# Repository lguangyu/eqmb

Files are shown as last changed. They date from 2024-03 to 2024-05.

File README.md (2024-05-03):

# Emergency Question Mark Button (EQMB)

For a certain professor that uses a lot of question marks when reviewing/commenting our manuscripts.
Some question marks are subject to lurk in the maintext because the said professor refuses to use the Word's "comment" feature. Those lurking question marks are unprecedented gifts to any editor whom they *may not* concern.

This project has an alt-name: the <b>EMERGENCY BUTTON for a certain PROFESSOR'S RAGE</b>, or <b><font color="#8080ff">EBPR</font></b>.

## Features

This is an application based on ESP32 microcontroller. It comes with a top Rage-Button, a BT control button, a micro-USB charging port and a power switch.

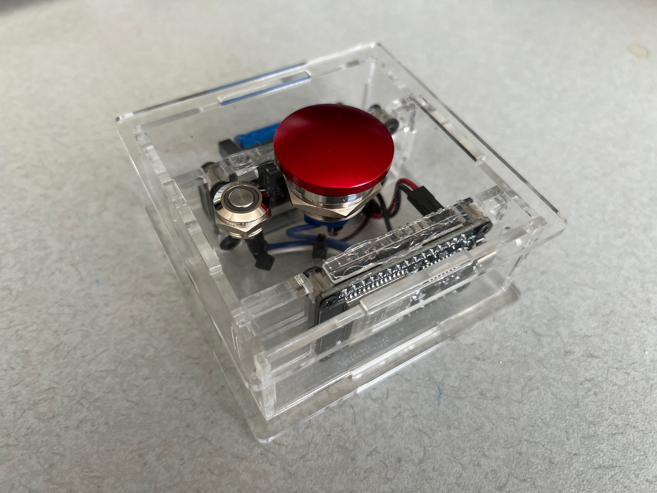
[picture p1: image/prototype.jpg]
Prototype


### Power

This device is powered by a single 16340 lithium battery that can be recharged from micro-USB. There is a power switch on the bottom side of the device.

### Rage-Button

When pressed, the top button sends a <kbd>?</kbd> character to the host computer. Follow-up presses within 750ms of the preceding one will send more <kbd>?</kbd>s, up to 6 in a single press. This feature is called "rage streak".

### Bluetooth (BT) Control Button

When the BT control button is pushed, the device will enter BT pairing mode (with blue LED flashing) for accepting new device pairings. A second push will exit the pairing mode.

Releasing the BT control button after holding it for over 5sec will trigger a hard reset of the device, deleting all paired devices.

### Sleep Mode

The device will enter sleep mode when left idle for over 2min. Push the BT control button can wake it up.

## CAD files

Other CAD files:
cad/box.dwg

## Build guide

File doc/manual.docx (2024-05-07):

# Emergency Button for a certain Professor’s Rage

# = Codename: EBPR =

# SYNOPSIS

A button for a certain professor to rage-press when reviewing manuscripts and abstracts. This button allows the certain professor to rapidly send “?” marks via Bluetooth. It is a significant time saver and emergency solution for imminent “?” satisfaction.

# QUICKSTART GUIDE

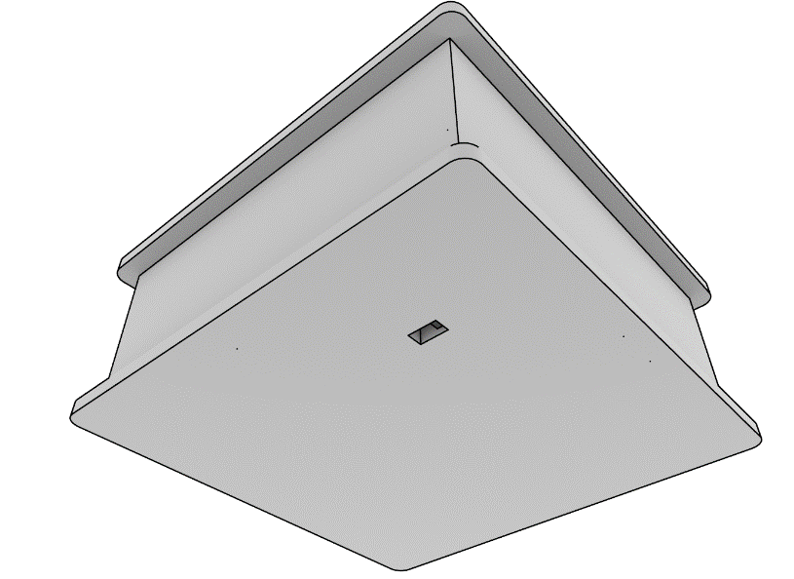
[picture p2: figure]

| (1) Switch on.
| (2) Tap to enter BT paring mode. Built-in LEDs will start to blink.

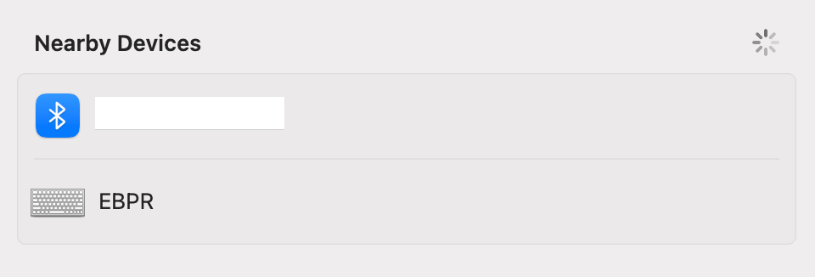
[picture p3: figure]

| (3) Connect via Bluetooth. For Mac, find more information about Bluetooth connection here (https://support.apple.com/guide/mac-help/connect-a-bluetooth-device-blth1004/mac); for Windows, here (https://support.microsoft.com/en-us/windows/pair-a-bluetooth-device-in-windows-2be7b51f-6ae9-b757-a3b9-95ee40c3e242).
| (4) Once connected, press the red button to enjoy the rage-pressing. The faster spamming this button, the more “?” will be sent.

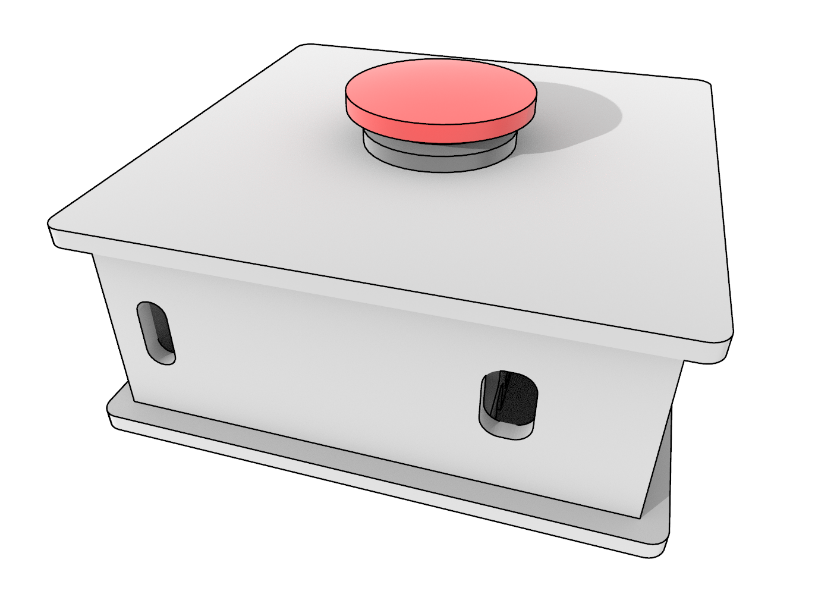
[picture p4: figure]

| Low battery In case of low battery, charging via micro-USB through this port. The LED near the battery will turn green when fully charged.
| Sleep mode Device will enter sleep mode after 120s of no action. Tap to wake it up.
| Bluetooth resetting While not in sleep mode, holding down this button for at least 10s to reset the Bluetooth pairing.

# TECHNICAL PARAMETERS

Weight | 200g (battery included)
Dimensions | 90mm (W) × 90mm (L) × 50mm (H)
MCU | 1× ESP32-WROOM
MCU VCC | 3.3V, internally regulated
Working current | Not rated
Max. transmit power | 21 dBm
Battery | 1× 16340 3.7V 2400mAh Li-ion battery.
Charging | 5V, ≤200mA
Charging port | 1× micro-USB

# OPEN-SOURCE ACCESSIBILITY

Project source: https://github.com/lguangyu/eqmb.git.

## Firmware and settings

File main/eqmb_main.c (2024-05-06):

/*
 * SPDX-FileCopyrightText: 2021-2022 Espressif Systems (Shanghai) CO LTD
 *
 * SPDX-License-Identifier: Unlicense OR CC0-1.0
 */

#include <stdio.h>
#include <stdlib.h>
#include <string.h>
#include <stdbool.h>
#include <assert.h>
#include "freertos/FreeRTOS.h"
#include "freertos/task.h"
#include "freertos/event_groups.h"
#include "esp_system.h"
#include "esp_timer.h"
#include "esp_sleep.h"
#include "esp_random.h"
#include "esp_event.h"
#include "esp_log.h"
#include "nvs_flash.h"
#include "esp_bt.h"

#include "esp_hidd_prf_api.h"
#include "esp_bt_defs.h"
#include "esp_gap_ble_api.h"
#include "esp_gatts_api.h"
#include "esp_gatt_defs.h"
#include "esp_bt_main.h"
#include "esp_bt_device.h"
#include "driver/gpio.h"
#include "driver/rtc_io.h"
#include "hid_dev.h"

/**
 * Brief:
 * This example Implemented BLE HID device profile related functions, in which the HID device
 * has 4 Reports (1 is mouse, 2 is keyboard and LED, 3 is Consumer Devices, 4 is Vendor devices).
 * Users can choose different reports according to their own application scenarios.
 * BLE HID profile inheritance and USB HID class.
 */

/**
 * Note:
 * 1. Win10 does not support vendor report , So SUPPORT_REPORT_VENDOR is always set to FALSE, it defines in hidd_le_prf_int.h
 * 2. Update connection parameters are not allowed during iPhone HID encryption, slave turns
 * off the ability to automatically update connection parameters during encryption.
 * 3. After our HID device is connected, the iPhones write 1 to the Report Characteristic Configuration Descriptor,
 * even if the HID encryption is not completed. This should actually be written 1 after the HID encryption is completed.
 * we modify the permissions of the Report Characteristic Configuration Descriptor to `ESP_GATT_PERM_READ | ESP_GATT_PERM_WRITE_ENCRYPTED`.
 * if you got `GATT_INSUF_ENCRYPTION` error, please ignore.
 */

#define TAG "EQMB"

// use this lock to access below variables if necessary
static SemaphoreHandle_t eqmb_ble_semaphore = NULL;
// pairing status
static bool eqmb_pairing_on = false;
static bool eqmb_pairing_gpio_pressed = false;
static QueueHandle_t eqmb_pairing_gpio_queue = NULL;
static TimerHandle_t eqmb_pairing_timer = NULL;
// bluetooth status
static bool eqmb_connected = false; // bool = only one connection
									// otherwise, should use a counter
static uint16_t hidd_conn_id;
static esp_bd_addr_t eqmb_current_remote_addr = {0};
// const static esp_bd_addr_t eqmb_static_local_addr = {0xd6, 0x3c, 0x1e, 0x0b, 0x73, 0x15};

// the RAGE-BUTTON!!!!! FINALLY
static QueueHandle_t eqmb_ragebtn_gpio_queue = NULL;
// this spec str list must have length of 2^n
#define EQMB_ENABLE_SPEC_STR 1 // comment out this line to disable special string
const static uint8_t eqmb_ragebtn_spec_str_len = 4;
extern const keyboard_cmd_t **eqmb_ragebtn_spec_str[4];

const static gpio_num_t eqmb_ragebtn_gpio_num = GPIO_NUM_27;	 // ? button for april to rage-press
const static gpio_num_t eqmb_pairing_led_gpio_num = GPIO_NUM_26; // led to indicate advertising
const static gpio_num_t eqmb_pairing_gpio_num = GPIO_NUM_25;	 // button to start pairing

// sleep
const static gpio_num_t eqmb_sleep_gpio_num = eqmb_pairing_gpio_num; // use the pairing button for wakeup
static TimerHandle_t eqmb_sleep_timer = NULL;
const static int eqmb_sleep_timer_duration = 120000 / portTICK_PERIOD_MS; // 2 minutes = 120,000 ms

// #define HIDD_DEVICE_NAME "EQMB"
#define HIDD_DEVICE_NAME "EBPR"
static uint8_t hidd_service_uuid128[] = {
	0xfb,
	0x34,
	0x9b,
	0x5f,
	0x80,
	0x00,
	0x00,
	0x80,
	0x00,
	0x10,
	0x00,
	0x00,
	0x12,
	0x18,
	0x00,
	0x00,
};

static esp_ble_adv_data_t hidd_adv_data = {
	.set_scan_rsp = false,
	.include_name = true,
	.include_txpower = false,
	.min_interval = 0x0006, // slave connection min interval, Time = min_interval * 1.25 msec
	.max_interval = 0x0010, // slave connection max interval, Time = max_interval * 1.25 msec
	.appearance = 0x03c1,	// HID Keyboard,
	.manufacturer_len = 0,
	.p_manufacturer_data = NULL,
	.service_data_len = 0,
	.p_service_data = NULL,
	.service_uuid_len = sizeof(hidd_service_uuid128),
	.p_service_uuid = hidd_service_uuid128,
	.flag = 0x6,
};

static esp_ble_adv_params_t hidd_adv_params = {
	.adv_int_min = 0x20,
	.adv_int_max = 0x30,
	.adv_type = ADV_TYPE_IND,
	.own_addr_type = BLE_ADDR_TYPE_PUBLIC,
	.channel_map = ADV_CHNL_ALL,
	.adv_filter_policy = ADV_FILTER_ALLOW_SCAN_WLST_CON_WLST,
};

static void IRAM_ATTR delay_microsecond(int64_t us)
{
	if (us == 0)
		return;
	int64_t start = esp_timer_get_time();
	int64_t end = start + us;
	if (end < start)
		// this is overflow, though we should not reach here since 2^63 us is
		// 292471 years
		return;
	while (esp_timer_get_time() < end)
		asm("nop"); // busy waiting, but ok within several us i guess
	return;
}

static void eqmb_sleep_timer_callback(TimerHandle_t xTimer)
{
	ESP_LOGI(TAG, "configuring sleep");
	// disable wifi and bluetooth
	esp_bluedroid_disable();
	esp_bt_controller_disable();
	// configure for wakeup
	esp_sleep_enable_ext0_wakeup(eqmb_sleep_gpio_num, 0);
	rtc_gpio_pullup_en(eqmb_sleep_gpio_num);
	rtc_gpio_pulldown_dis(eqmb_sleep_gpio_num);
	// start deepsleep
	ESP_LOGI(TAG, "start sleep");
	esp_deep_sleep_start();
	return;
}

static void eqmb_sleep_timer_init(void)
{
	eqmb_sleep_timer = xTimerCreate("eqmb_sleep_timer",
									eqmb_sleep_timer_duration,
									pdFALSE, NULL,
									eqmb_sleep_timer_callback);
	assert(eqmb_sleep_timer != NULL);
	xTimerStart(eqmb_sleep_timer, 0);
	return;
}

static void eqmb_pairing_led_task(void *arg)
{
	bool blink_status = false;
	bool led_on;
	while (1)
	{
		blink_status = !blink_status;
		led_on = eqmb_pairing_gpio_pressed || (blink_status && eqmb_pairing_on);
		gpio_set_level(GPIO_NUM_2, led_on);
		gpio_set_level(eqmb_pairing_led_gpio_num, led_on);
		vTaskDelay(200 / portTICK_PERIOD_MS);
	}
	return;
}

static void eqmb_pairing_start(void)
{
	xSemaphoreTake(eqmb_ble_semaphore, portMAX_DELAY);
	if (!eqmb_pairing_on)
	{
		ESP_LOGI(TAG, "start pairing mode");
		eqmb_pairing_on = true;
		hidd_adv_params.adv_filter_policy = ADV_FILTER_ALLOW_SCAN_ANY_CON_ANY;
		esp_ble_gap_stop_advertising();
		esp_ble_gap_start_advertising(&hidd_adv_params);
		xTimerStart(eqmb_pairing_timer, 0);
	}
	xSemaphoreGive(eqmb_ble_semaphore);
	return;
}

static void eqmb_pairing_stop(void)
{
	xSemaphoreTake(eqmb_ble_semaphore, portMAX_DELAY);
	if (eqmb_pairing_on)
	{
		ESP_LOGI(TAG, "stop pairing mode");
		eqmb_pairing_on = false;
		hidd_adv_params.adv_filter_policy = ADV_FILTER_ALLOW_SCAN_WLST_CON_WLST;
		esp_ble_gap_stop_advertising();
		esp_ble_gap_start_advertising(&hidd_adv_params);
		xTimerStop(eqmb_pairing_timer, 0);
	}
	xSemaphoreGive(eqmb_ble_semaphore);
	return;
}

static void eqmb_pairing_timer_callback(TimerHandle_t xTimer)
{
	ESP_LOGI(TAG, "pairing mode timeout");
	eqmb_pairing_stop();
	return;
}

static void esp_ble_clear_bond_device(void)
{
	int bond_dev_num = esp_ble_get_bond_device_num();
	esp_ble_bond_dev_t *bond_dev_list = (esp_ble_bond_dev_t *)malloc(bond_dev_num * sizeof(esp_ble_bond_dev_t));
	esp_ble_get_bond_device_list(&bond_dev_num, bond_dev_list);
	for (int i = 0; i < bond_dev_num; i++)
		esp_ble_remove_bond_device(bond_dev_list[i].bd_addr);
	free(bond_dev_list);
	return;
}

static void eqmb_pairing_short_press_handler(void)
{
	if (!eqmb_pairing_on)
		eqmb_pairing_start();
	else
		eqmb_pairing_stop();
	return;
}

static void eqmb_pairing_long_press_handler(void)
{
	// long press reset the bond devices connections, whitelist
	xSemaphoreTake(eqmb_ble_semaphore, portMAX_DELAY);
	eqmb_pairing_on = false;
	xSemaphoreGive(eqmb_ble_semaphore);
	esp_ble_gap_disconnect(eqmb_current_remote_addr);
	esp_ble_clear_bond_device();
	esp_ble_gap_clear_whitelist();
	// add some delay for the bond device and whitelist update to take place
	vTaskDelay(100 / portTICK_PERIOD_MS); // 100ms
	// then reset mcu
	// eqmb_pairing_start();
	esp_restart();
	return;
}

static void eqmb_pairing_gpio_task(void *arg)
{
	int64_t last_isr_time = 0, curr_isr_time;
	uint32_t press_time = 0;
	bool is_release_event;

	while (1)
	{
		if (xQueueReceive(eqmb_pairing_gpio_queue, NULL, portMAX_DELAY))
		{
			curr_isr_time = esp_timer_get_time();
			// jitter protection
			// if registered too quickly, ignore
			if (curr_isr_time - last_isr_time < 20000) // 20ms
				continue;
			// now consider it as a valid press
			last_isr_time = curr_isr_time;
			if (eqmb_sleep_timer)
				xTimerReset(eqmb_sleep_timer, 0);
			// delay 10ms then test the pin level
			delay_microsecond(10000); // 10ms debounce
			is_release_event = gpio_get_level(eqmb_pairing_gpio_num);
			if ((!eqmb_pairing_gpio_pressed) && (!is_release_event))
			{
				// start of press timing
				press_time = curr_isr_time;
				eqmb_pairing_gpio_pressed = true;
			}
			else if (eqmb_pairing_gpio_pressed && is_release_event)
			{
				// end of press timing
				eqmb_pairing_gpio_pressed = false;
				// check press duration (5s mark)
				press_time = curr_isr_time - press_time;
				if (press_time < 5000000)
				{
					ESP_LOGI(TAG, "short press detected");
					eqmb_pairing_short_press_handler();
				}
				else
				{
					ESP_LOGI(TAG, "long press detected");
					eqmb_pairing_long_press_handler();
				}
			}
			else
			{
				// something unexpected happened, but we need to reset the state
				eqmb_pairing_gpio_pressed = false;
			}
		}
	}
	return;
}

static void IRAM_ATTR eqmb_pairing_gpio_isr(void *arg)
{
	// jitter protection in handler
	xQueueSendFromISR(eqmb_pairing_gpio_queue, NULL, NULL);
	return;
}

static void eqmb_pairing_gpio_init(void)
{
	// leds
	gpio_set_direction(GPIO_NUM_2, GPIO_MODE_OUTPUT);
	gpio_set_direction(eqmb_pairing_led_gpio_num, GPIO_MODE_OUTPUT);
	// create tasks
	eqmb_pairing_gpio_queue = xQueueCreate(1, 0);
	assert(eqmb_pairing_gpio_queue != NULL);
	eqmb_pairing_timer = xTimerCreate("eqmb_pairing_timer",
									  30000 / portTICK_PERIOD_MS,
									  pdFALSE, NULL,
									  eqmb_pairing_timer_callback);
	assert(eqmb_pairing_timer != NULL);
	xTaskCreate(&eqmb_pairing_gpio_task, "eqmb_pairing_gpio_task", 2048, NULL, 5, NULL);
	xTaskCreate(&eqmb_pairing_led_task, "eqmb_pairing_led_task", 1024, NULL, 5, NULL);
	// pairing pin
	gpio_config_t io_conf;
	io_conf.intr_type = GPIO_INTR_ANYEDGE;
	io_conf.mode = GPIO_MODE_INPUT;
	io_conf.pin_bit_mask = 1ULL << eqmb_pairing_gpio_num;
	io_conf.pull_down_en = GPIO_PULLDOWN_DISABLE;
	io_conf.pull_up_en = GPIO_PULLUP_ENABLE;
	gpio_config(&io_conf);
	gpio_isr_handler_add(eqmb_pairing_gpio_num, eqmb_pairing_gpio_isr, NULL);
	return;
}

static void eqmb_ragebtn_send_key(uint8_t act_streak)
{
	const static keyboard_cmd_t **sstr_word_p = NULL;	// NULL = send normal ?
	static int spec_str_due = 11;						// this is a magical number
	static keyboard_cmd_t qm_buf = {HID_KEY_FWD_SLASH}; // used send regular ?

#ifndef EQMB_ENABLE_SPEC_STR
	for (int i = 0; i < act_streak; i++)
	{
		esp_hidd_send_keyboard_value(hidd_conn_id, 0x02, &qm_buf, 1);
		esp_hidd_send_keyboard_value(hidd_conn_id, 0x00, &qm_buf, 0);
	}
#else
	// re-fill value of spec_str_due
	if ((sstr_word_p == NULL) && (spec_str_due == 0))
	{
		spec_str_due = esp_random() & 0x1f;
		if (spec_str_due < 0x10) // at least 16 presses before special string
			spec_str_due += 0x10;
	}
	// check if need to send special string
	if (sstr_word_p == NULL)
	{
		// send regular ?, act_streak increase the number of ?
		for (int i = 0; i <= act_streak; i++)
		{
			esp_hidd_send_keyboard_value(hidd_conn_id, 0x02, &qm_buf, 1);
			esp_hidd_send_keyboard_value(hidd_conn_id, 0x00, &qm_buf, 0);
		}
		spec_str_due--;
		if ((spec_str_due == 0) && (eqmb_ragebtn_spec_str_len > 0))
		{
			// next press will send special string
			// determine the next special string
			sstr_word_p = eqmb_ragebtn_spec_str[esp_random() & (eqmb_ragebtn_spec_str_len - 1)];
		}
	}
	else
	{
		// send special string
		if (!*sstr_word_p)
			return;
		// send the keys
		const keyboard_cmd_t *c = *sstr_word_p;
		while (*c) // NULL-terminated
		{
			key_mask_t mask = ((*c == HID_KEY_SPACEBAR) || (*c == HID_KEY_SGL_QUOTE) || (*c == HID_KEY_DOT)) ? 0x00 : 0x02;
			esp_hidd_send_keyboard_value(hidd_conn_id, mask, (keyboard_cmd_t *)c, 1);
			esp_hidd_send_keyboard_value(hidd_conn_id, 0x00, (keyboard_cmd_t *)c, 0);
			c++;
		}
		// move to next word
		sstr_word_p++;
		if (!*sstr_word_p)
			// end of the special string
			sstr_word_p = NULL;
	}
#endif // EQMB_ENABLE_SPEC_STR
	return;
}

static void eqmb_ragebtn_gpio_task(void *arg)
{
	int64_t last_rage_time = 0, curr_isr_time; // last_rage_time = last_isr_time
	uint8_t act_streak = 0;
	while (1)
	{
		if (xQueueReceive(eqmb_ragebtn_gpio_queue, NULL, portMAX_DELAY))
		{
			curr_isr_time = esp_timer_get_time();
			// jitter protection
			// if registered too quickly, ignore
			if (curr_isr_time - last_rage_time < 50000) // 50ms
				continue;
			// delay 10ms then test the pin level
			delay_microsecond(10000); // 10ms debounce
			if (gpio_get_level(eqmb_ragebtn_gpio_num) == 1)
				continue;
			// now consider it as a valid press
			if (eqmb_sleep_timer)
				xTimerReset(eqmb_sleep_timer, 0);
			// we still need the last_rage_time for the streak detection, so
			// no update here
			if (!eqmb_connected)
				continue;
			if (curr_isr_time - last_rage_time < 750000)
			{
				// 750ms grace period for 'rage mode', considering the agility
				// stat of the certain professor

				// streak is exiciting! need 16 !s
				ESP_LOGI(TAG, "RAGE BUTTON STREAK!!!!!!!!!!!!!!!!");
				act_streak += (act_streak < 5) ? 1 : 0; // max 5, for 6 chars
			}
			else
			{
				// a little bit of boring here, tbh; so only 8 !s
				ESP_LOGI(TAG, "RAGE BUTTON PRESSED!!!!!!!!");
				act_streak = 0;
			}
			// update last_rage_time here
			last_rage_time = curr_isr_time;
			// 0x02 = LSHIFT modifier
			// use time as the random number
			eqmb_ragebtn_send_key(act_streak);
		}
	}
	return;
}

static void IRAM_ATTR eqmb_ragebtn_gpio_isr(void *arg)
{
	// jitter protection in handler
	xQueueSendToBackFromISR(eqmb_ragebtn_gpio_queue, NULL, pdFALSE);
	return;
}

static void eqmb_ragebtn_gpio_init(void)
{
	// create tasks
	eqmb_ragebtn_gpio_queue = xQueueCreate(1, 0);
	assert(eqmb_ragebtn_gpio_queue != NULL);
	xTaskCreate(&eqmb_ragebtn_gpio_task, "eqmb_ragebtn_gpio_task", 2048, NULL, 10, NULL);
	// rage button pin
	gpio_config_t io_conf;
	io_conf.intr_type = GPIO_INTR_NEGEDGE;
	io_conf.mode = GPIO_MODE_INPUT;
	io_conf.pin_bit_mask = 1ULL << eqmb_ragebtn_gpio_num;
	io_conf.pull_down_en = GPIO_PULLDOWN_DISABLE;
	io_conf.pull_up_en = GPIO_PULLUP_ENABLE;
	gpio_config(&io_conf);
	// gpio_install_isr_service(0);
	gpio_isr_handler_add(eqmb_ragebtn_gpio_num, eqmb_ragebtn_gpio_isr, NULL);
	return;
}

static void hidd_event_callback(esp_hidd_cb_event_t event, esp_hidd_cb_param_t *param)
{
	switch (event)
	{
	case ESP_HIDD_EVENT_REG_FINISH:
		if (param->init_finish.state == ESP_HIDD_INIT_OK)
		{
			esp_ble_gap_set_device_name(HIDD_DEVICE_NAME);
			esp_ble_gap_config_adv_data(&hidd_adv_data);
		}
		break;
	case ESP_BAT_EVENT_REG:
		break;
	case ESP_HIDD_EVENT_DEINIT_FINISH:
		break;
	case ESP_HIDD_EVENT_BLE_CONNECT:
		ESP_LOGI(TAG, "ESP_HIDD_EVENT_BLE_CONNECT");
		hidd_conn_id = param->connect.conn_id;
		break;
	case ESP_HIDD_EVENT_BLE_DISCONNECT:
		ESP_LOGI(TAG, "ESP_HIDD_EVENT_BLE_DISCONNECT");
		eqmb_connected = false;
		esp_ble_gap_start_advertising(&hidd_adv_params);
		break;
	case ESP_HIDD_EVENT_BLE_VENDOR_REPORT_WRITE_EVT:
		ESP_LOGI(TAG, "%s, ESP_HIDD_EVENT_BLE_VENDOR_REPORT_WRITE_EVT", __func__);
		ESP_LOG_BUFFER_HEX(TAG, param->vendor_write.data, param->vendor_write.length);
		break;
	case ESP_HIDD_EVENT_BLE_LED_REPORT_WRITE_EVT:
		ESP_LOGI(TAG, "ESP_HIDD_EVENT_BLE_LED_REPORT_WRITE_EVT");
		ESP_LOG_BUFFER_HEX(TAG, param->led_write.data, param->led_write.length);
		break;
	default:
		break;
	}
	return;
}

static void gap_event_handler(esp_gap_ble_cb_event_t event, esp_ble_gap_cb_param_t *param)
{
	switch (event)
	{
	case ESP_GAP_BLE_ADV_DATA_SET_COMPLETE_EVT:
		if (!eqmb_connected)
			esp_ble_gap_start_advertising(&hidd_adv_params);
		break;
	case ESP_GAP_BLE_SEC_REQ_EVT:
		for (int i = 0; i < ESP_BD_ADDR_LEN; i++)
			ESP_LOGD(TAG, "%x:", param->ble_security.ble_req.bd_addr[i]);
		ESP_ERROR_CHECK(esp_ble_gap_security_rsp(param->ble_security.ble_req.bd_addr, true));
		break;
	case ESP_GAP_BLE_AUTH_CMPL_EVT:
		esp_bd_addr_t bd_addr;
		memcpy(bd_addr, param->ble_security.auth_cmpl.bd_addr, sizeof(esp_bd_addr_t));
		ESP_LOGI(TAG, "remote BD_ADDR: %08x%04x",
				 (bd_addr[0] << 24) + (bd_addr[1] << 16) + (bd_addr[2] << 8) + bd_addr[3],
				 (bd_addr[4] << 8) + bd_addr[5]);
		ESP_LOGI(TAG, "address type = %d", param->ble_security.auth_cmpl.addr_type);
		ESP_LOGI(TAG, "pair status = %s", param->ble_security.auth_cmpl.success ? "success" : "fail");
		if (!param->ble_security.auth_cmpl.success)
		{
			ESP_LOGE(TAG, "fail reason = 0x%x", param->ble_security.auth_cmpl.fail_reason);
			break;
		}
		// disconnect the old device when connected if applicable
		if (eqmb_connected && memcmp(bd_addr, eqmb_current_remote_addr, sizeof(esp_bd_addr_t)))
		{
			esp_ble_gap_disconnect(eqmb_current_remote_addr);
			esp_ble_remove_bond_device(eqmb_current_remote_addr);
			esp_ble_gap_update_whitelist(false, eqmb_current_remote_addr, BLE_ADDR_TYPE_PUBLIC);
		}
		// update new connection status
		xSemaphoreTake(eqmb_ble_semaphore, portMAX_DELAY);
		eqmb_connected = true;
		memcpy(eqmb_current_remote_addr, bd_addr, sizeof(esp_bd_addr_t));
		xSemaphoreGive(eqmb_ble_semaphore);
		esp_ble_gap_update_whitelist(true, bd_addr, BLE_ADDR_TYPE_PUBLIC);
		eqmb_pairing_stop();
		break;
	default:
		break;
	}
}

static void eqmb_nvs_flash_init(void)
{
	esp_err_t ret;
	ret = nvs_flash_init();
	if (ret == ESP_ERR_NVS_NO_FREE_PAGES || ret == ESP_ERR_NVS_NEW_VERSION_FOUND)
	{
		ESP_ERROR_CHECK(nvs_flash_erase());
		ret = nvs_flash_init();
	}
	ESP_ERROR_CHECK(ret);
	return;
}

static void eqmb_bt_controller_init(void)
{
	ESP_ERROR_CHECK(esp_bt_controller_mem_release(ESP_BT_MODE_CLASSIC_BT));
	esp_bt_controller_config_t bt_cfg = BT_CONTROLLER_INIT_CONFIG_DEFAULT();
	ESP_ERROR_CHECK(esp_bt_controller_init(&bt_cfg));
	ESP_ERROR_CHECK(esp_bt_controller_enable(ESP_BT_MODE_BLE));
	return;
}

static void eqmb_bluedroid_init(void)
{
	esp_bluedroid_config_t bluedroid_cfg = BT_BLUEDROID_INIT_CONFIG_DEFAULT();
	ESP_ERROR_CHECK(esp_bluedroid_init_with_cfg(&bluedroid_cfg));
	ESP_ERROR_CHECK(esp_bluedroid_enable());
	return;
}

static void eqmb_gap_init(void)
{
	/* set the security iocap & auth_req & key size & init key response key parameters to the stack*/
	esp_ble_auth_req_t auth_req = ESP_LE_AUTH_BOND; // bonding with peer device after authentication
	esp_ble_io_cap_t iocap = ESP_IO_CAP_NONE;		// set the IO capability to No output No input
	uint8_t key_size = 16;							// the key size should be 7~16 bytes
	uint8_t init_key = ESP_BLE_ENC_KEY_MASK | ESP_BLE_ID_KEY_MASK;
	uint8_t rsp_key = ESP_BLE_ENC_KEY_MASK | ESP_BLE_ID_KEY_MASK;
	esp_ble_gap_set_security_param(ESP_BLE_SM_AUTHEN_REQ_MODE, &auth_req, sizeof(uint8_t));
	esp_ble_gap_set_security_param(ESP_BLE_SM_IOCAP_MODE, &iocap, sizeof(uint8_t));
	esp_ble_gap_set_security_param(ESP_BLE_SM_MAX_KEY_SIZE, &key_size, sizeof(uint8_t));
	/* If your BLE device act as a Slave, the init_key means you hope which types of key of the master should distribute to you,
	and the response key means which key you can distribute to the Master;
	If your BLE device act as a master, the response key means you hope which types of key of the slave should distribute to you,
	and the init key means which key you can distribute to the slave. */
	esp_ble_gap_set_security_param(ESP_BLE_SM_SET_INIT_KEY, &init_key, sizeof(uint8_t));
	esp_ble_gap_set_security_param(ESP_BLE_SM_SET_RSP_KEY, &rsp_key, sizeof(uint8_t));
	return;
}

static void eqmb_load_bond_devices_as_whitelist(void)
{
	int bond_dev_num = esp_ble_get_bond_device_num();
	esp_ble_bond_dev_t *bond_dev_list = (esp_ble_bond_dev_t *)malloc(bond_dev_num * sizeof(esp_ble_bond_dev_t));
	esp_ble_get_bond_device_list(&bond_dev_num, bond_dev_list);
	for (int i = 0; i < bond_dev_num; i++)
	{
		ESP_ERROR_CHECK(esp_ble_gap_update_whitelist(true, bond_dev_list[i].bd_addr, BLE_ADDR_TYPE_PUBLIC));
		ESP_LOGI(TAG, "adding bond device to whitelist: %08x%04x",
				 (bond_dev_list[i].bd_addr[0] << 24) + (bond_dev_list[i].bd_addr[1] << 16) + (bond_dev_list[i].bd_addr[2] << 8) + bond_dev_list[i].bd_addr[3],
				 (bond_dev_list[i].bd_addr[4] << 8) + bond_dev_list[i].bd_addr[5]);
	}
	free(bond_dev_list);
	return;
}

void app_main(void)
{
	if (esp_sleep_get_wakeup_cause())
		// just reset, don't bother with other stuff
		esp_restart();

	eqmb_ble_semaphore = xSemaphoreCreateMutex();
	assert(eqmb_ble_semaphore != NULL);
	// bt device init
	eqmb_nvs_flash_init();
	eqmb_bt_controller_init();
	eqmb_bluedroid_init();
	// ESP_ERROR_CHECK(esp_ble_gap_set_rand_addr((uint8_t *)eqmb_static_local_addr));
	ESP_ERROR_CHECK(esp_hidd_profile_init());
	eqmb_load_bond_devices_as_whitelist();
	// register the callback function to the gap module
	esp_ble_gap_register_callback(gap_event_handler);
	esp_hidd_register_callbacks(hidd_event_callback);
	eqmb_gap_init();
	// init gpio
	eqmb_sleep_timer_init();
	gpio_install_isr_service(0);
	eqmb_pairing_gpio_init();
	eqmb_ragebtn_gpio_init();

	vTaskDelay(portMAX_DELAY);
	return;
}

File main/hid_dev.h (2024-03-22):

/*
 * SPDX-FileCopyrightText: 2021-2022 Espressif Systems (Shanghai) CO LTD
 *
 * SPDX-License-Identifier: Unlicense OR CC0-1.0
 */

#ifndef HID_DEV_H__
#define HID_DEV_H__

#include "hidd_le_prf_int.h"

#ifdef __cplusplus
extern "C"
{
#endif

/* HID Report type */
#define HID_TYPE_INPUT 1
#define HID_TYPE_OUTPUT 2
#define HID_TYPE_FEATURE 3

// HID Keyboard/Keypad Usage IDs (subset of the codes available in the USB HID Usage Tables spec)
#define HID_KEY_RESERVED 0		// No event inidicated
#define HID_KEY_A 4				// Keyboard a and A
#define HID_KEY_B 5				// Keyboard b and B
#define HID_KEY_C 6				// Keyboard c and C
#define HID_KEY_D 7				// Keyboard d and D
#define HID_KEY_E 8				// Keyboard e and E
#define HID_KEY_F 9				// Keyboard f and F
#define HID_KEY_G 10			// Keyboard g and G
#define HID_KEY_H 11			// Keyboard h and H
#define HID_KEY_I 12			// Keyboard i and I
#define HID_KEY_J 13			// Keyboard j and J
#define HID_KEY_K 14			// Keyboard k and K
#define HID_KEY_L 15			// Keyboard l and L
#define HID_KEY_M 16			// Keyboard m and M
#define HID_KEY_N 17			// Keyboard n and N
#define HID_KEY_O 18			// Keyboard o and O
#define HID_KEY_P 19			// Keyboard p and p
#define HID_KEY_Q 20			// Keyboard q and Q
#define HID_KEY_R 21			// Keyboard r and R
#define HID_KEY_S 22			// Keyboard s and S
#define HID_KEY_T 23			// Keyboard t and T
#define HID_KEY_U 24			// Keyboard u and U
#define HID_KEY_V 25			// Keyboard v and V
#define HID_KEY_W 26			// Keyboard w and W
#define HID_KEY_X 27			// Keyboard x and X
#define HID_KEY_Y 28			// Keyboard y and Y
#define HID_KEY_Z 29			// Keyboard z and Z
#define HID_KEY_1 30			// Keyboard 1 and !
#define HID_KEY_2 31			// Keyboard 2 and @
#define HID_KEY_3 32			// Keyboard 3 and #
#define HID_KEY_4 33			// Keyboard 4 and %
#define HID_KEY_5 34			// Keyboard 5 and %
#define HID_KEY_6 35			// Keyboard 6 and ^
#define HID_KEY_7 36			// Keyboard 7 and &
#define HID_KEY_8 37			// Keyboard 8 and *
#define HID_KEY_9 38			// Keyboard 9 and (
#define HID_KEY_0 39			// Keyboard 0 and )
#define HID_KEY_RETURN 40		// Keyboard Return (ENTER)
#define HID_KEY_ESCAPE 41		// Keyboard ESCAPE
#define HID_KEY_DELETE 42		// Keyboard DELETE (Backspace)
#define HID_KEY_TAB 43			// Keyboard Tab
#define HID_KEY_SPACEBAR 44		// Keyboard Spacebar
#define HID_KEY_MINUS 45		// Keyboard - and (underscore)
#define HID_KEY_EQUAL 46		// Keyboard = and +
#define HID_KEY_LEFT_BRKT 47	// Keyboard [ and {
#define HID_KEY_RIGHT_BRKT 48	// Keyboard ] and }
#define HID_KEY_BACK_SLASH 49	// Keyboard \ and |
#define HID_KEY_SEMI_COLON 51	// Keyboard ; and :
#define HID_KEY_SGL_QUOTE 52	// Keyboard ' and "
#define HID_KEY_GRV_ACCENT 53	// Keyboard Grave Accent and Tilde
#define HID_KEY_COMMA 54		// Keyboard , and <
#define HID_KEY_DOT 55			// Keyboard . and >
#define HID_KEY_FWD_SLASH 56	// Keyboard / and ?
#define HID_KEY_CAPS_LOCK 57	// Keyboard Caps Lock
#define HID_KEY_F1 58			// Keyboard F1
#define HID_KEY_F2 59			// Keyboard F2
#define HID_KEY_F3 60			// Keyboard F3
#define HID_KEY_F4 61			// Keyboard F4
#define HID_KEY_F5 62			// Keyboard F5
#define HID_KEY_F6 63			// Keyboard F6
#define HID_KEY_F7 64			// Keyboard F7
#define HID_KEY_F8 65			// Keyboard F8
#define HID_KEY_F9 66			// Keyboard F9
#define HID_KEY_F10 67			// Keyboard F10
#define HID_KEY_F11 68			// Keyboard F11
#define HID_KEY_F12 69			// Keyboard F12
#define HID_KEY_PRNT_SCREEN 70	// Keyboard Print Screen
#define HID_KEY_SCROLL_LOCK 71	// Keyboard Scroll Lock
#define HID_KEY_PAUSE 72		// Keyboard Pause
#define HID_KEY_INSERT 73		// Keyboard Insert
#define HID_KEY_HOME 74			// Keyboard Home
#define HID_KEY_PAGE_UP 75		// Keyboard PageUp
#define HID_KEY_DELETE_FWD 76	// Keyboard Delete Forward
#define HID_KEY_END 77			// Keyboard End
#define HID_KEY_PAGE_DOWN 78	// Keyboard PageDown
#define HID_KEY_RIGHT_ARROW 79	// Keyboard RightArrow
#define HID_KEY_LEFT_ARROW 80	// Keyboard LeftArrow
#define HID_KEY_DOWN_ARROW 81	// Keyboard DownArrow
#define HID_KEY_UP_ARROW 82		// Keyboard UpArrow
#define HID_KEY_NUM_LOCK 83		// Keypad Num Lock and Clear
#define HID_KEY_DIVIDE 84		// Keypad /
#define HID_KEY_MULTIPLY 85		// Keypad *
#define HID_KEY_SUBTRACT 86		// Keypad -
#define HID_KEY_ADD 87			// Keypad +
#define HID_KEY_ENTER 88		// Keypad ENTER
#define HID_KEYPAD_1 89			// Keypad 1 and End
#define HID_KEYPAD_2 90			// Keypad 2 and Down Arrow
#define HID_KEYPAD_3 91			// Keypad 3 and PageDn
#define HID_KEYPAD_4 92			// Keypad 4 and Lfet Arrow
#define HID_KEYPAD_5 93			// Keypad 5
#define HID_KEYPAD_6 94			// Keypad 6 and Right Arrow
#define HID_KEYPAD_7 95			// Keypad 7 and Home
#define HID_KEYPAD_8 96			// Keypad 8 and Up Arrow
#define HID_KEYPAD_9 97			// Keypad 9 and PageUp
#define HID_KEYPAD_0 98			// Keypad 0 and Insert
#define HID_KEYPAD_DOT 99		// Keypad . and Delete
#define HID_KEY_MUTE 127		// Keyboard Mute
#define HID_KEY_VOLUME_UP 128	// Keyboard Volume up
#define HID_KEY_VOLUME_DOWN 129 // Keyboard Volume down
#define HID_KEY_LEFT_CTRL 224	// Keyboard LeftContorl
#define HID_KEY_LEFT_SHIFT 225	// Keyboard LeftShift
#define HID_KEY_LEFT_ALT 226	// Keyboard LeftAlt
#define HID_KEY_LEFT_GUI 227	// Keyboard LeftGUI
#define HID_KEY_RIGHT_CTRL 228	// Keyboard RightContorl
#define HID_KEY_RIGHT_SHIFT 229 // Keyboard RightShift
#define HID_KEY_RIGHT_ALT 230	// Keyboard RightAlt
#define HID_KEY_RIGHT_GUI 231	// Keyboard RightGUI
	typedef uint8_t keyboard_cmd_t;

#define HID_MOUSE_LEFT 253
#define HID_MOUSE_MIDDLE 254
#define HID_MOUSE_RIGHT 255
	typedef uint8_t mouse_cmd_t;

// HID Consumer Usage IDs (subset of the codes available in the USB HID Usage Tables spec)
#define HID_CONSUMER_POWER 48 // Power
#define HID_CONSUMER_RESET 49 // Reset
#define HID_CONSUMER_SLEEP 50 // Sleep

#define HID_CONSUMER_MENU 64		  // Menu
#define HID_CONSUMER_SELECTION 128	  // Selection
#define HID_CONSUMER_ASSIGN_SEL 129	  // Assign Selection
#define HID_CONSUMER_MODE_STEP 130	  // Mode Step
#define HID_CONSUMER_RECALL_LAST 131  // Recall Last
#define HID_CONSUMER_QUIT 148		  // Quit
#define HID_CONSUMER_HELP 149		  // Help
#define HID_CONSUMER_CHANNEL_UP 156	  // Channel Increment
#define HID_CONSUMER_CHANNEL_DOWN 157 // Channel Decrement
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

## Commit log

2024-03-22 pairing button
2024-03-23 rage button action
2024-03-24 box cad for laser cut
    [box.dwg]
2024-03-24 update jitter protection code
    [eqmb_main.c]
2024-04-19 update box cad
    [box.dwg]
2024-05-03 update cad
    [box.dwg]
2024-05-03 added prototype image
2024-05-06 revert to public address
    [eqmb_main.c]
2024-05-07 update cad draw
    [box.dwg]
